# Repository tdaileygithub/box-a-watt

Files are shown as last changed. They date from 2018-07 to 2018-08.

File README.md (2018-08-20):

# box-a-watt

killawatt P4400 with 3d printed box cover, image processing and emoncms display of power usage.

# Parts List [work in progress]

- [$20 - P3 P4400 kill a watt](https://www.amazon.com/P3-P4400-Electricity-Usage-Monitor/dp/B00009MDBU)
- [$5 - Lowe's - Black Solar LED Path Light](https://www.lowes.com/pd/Portfolio-4x-Brighter-4-8-Lumen-Black-Solar-LED-Path-Light/1000398433)
- [$10 - Pi Zero W](https://www.adafruit.com/product/3400)
- [$2 - LED Backlight Small](https://www.adafruit.com/product/1626)

**Total** : $37

# Pi Setup

## Disable red camera capture led

	sudo nano /boot/config.txt
	disable_camera_led=1
	sudo reboot

# [Emoncms](https://emoncms.org) setup

## Install Emoncms package dependencies 

	sudo apt-get install apache2 mysql-server mysql-client php libapache2-mod-php php-mysql php-curl php-pear php-dev php-mcrypt php-json git-core redis-server build-essential -y

## mysql installation

	sudo mysql_secure_installation
	sudo mysqld --initialize
	sudo mysqladmin -p -u root version

	sudo mysql -u root -p
	CREATE DATABASE emoncms DEFAULT CHARACTER SET utf8;
	CREATE USER 'emoncms'@'localhost' IDENTIFIED BY 'YOUR_SECURE_PASSWORD_HERE';
	GRANT ALL ON emoncms.* TO 'emoncms'@'localhost';
	flush privileges;
	exit

## apache and php configuration

	sudo pear channel-discover pear.swiftmailer.org
	sudo pecl install swift/swift redis
	printf "extension=redis.so" | sudo tee /etc/php/7.0/mods-available/redis.ini 1>&2

	sudo phpenmod redis
	sudo a2enmod rewrite
	sudo cat <<EOF >> /etc/apache2/sites-available/emoncms.conf
	<Directory /var/www/html/emoncms>
	    Options FollowSymLinks
	    AllowOverride All
	    DirectoryIndex index.php
	    Order allow,deny
	    Allow from all
	</Directory>
	EOF
	sudo echo 'ServerName localhost' >> /etc/apache2/apache2.conf
	sudo a2ensite emoncms
	sudo service apache2 reload

	cd /var/www/
	sudo chown $USER html
	cd html
	git clone -b stable https://github.com/emoncms/emoncms.git
	cd /var/www/html/emoncms
	git pull

	sudo mkdir /var/lib/phpfiwa
	sudo mkdir /var/lib/phpfina
	sudo mkdir /var/lib/phptimeseries

	sudo chown www-data:root /var/lib/phpfiwa
	sudo chown www-data:root /var/lib/phpfina
	sudo chown www-data:root /var/lib/phptimeseries

	cd /var/www/html/emoncms/Modules
	git clone https://github.com/emoncms/dashboard.git
	git clone https://github.com/emoncms/app.git
	
	sudo touch /var/log/emoncms.log
	sudo chmod 666 /var/log/emoncms.log

## emoncms configuration

	cd /var/www/html/emoncms/
	cp default.settings.php settings.php

	nano settings.php
	$username = "emoncms";
	$password = "YOUR_SECURE_PASSWORD_HERE";
	$server   = "localhost";
	$database = "emoncms";

	http://localhost/emoncms/

# [ssocr](https://github.com/auerswal/ssocr)

[ssorc manual](https://www.unix-ag.uni-kl.de/~auerswal/ssocr/)

Used to process images captured with raspistill.

## Install ssocr dependencies 

	sudo apt-get install libimlib2-dev

## make

	cd ssocr
	make

## example command

 	./ssocr -v -d -1 -P -S -D -t 20 crop 650 410 600 500  remove_isolated erosion 3 opening 3 ../29_07_2018_00_58_47.jpg

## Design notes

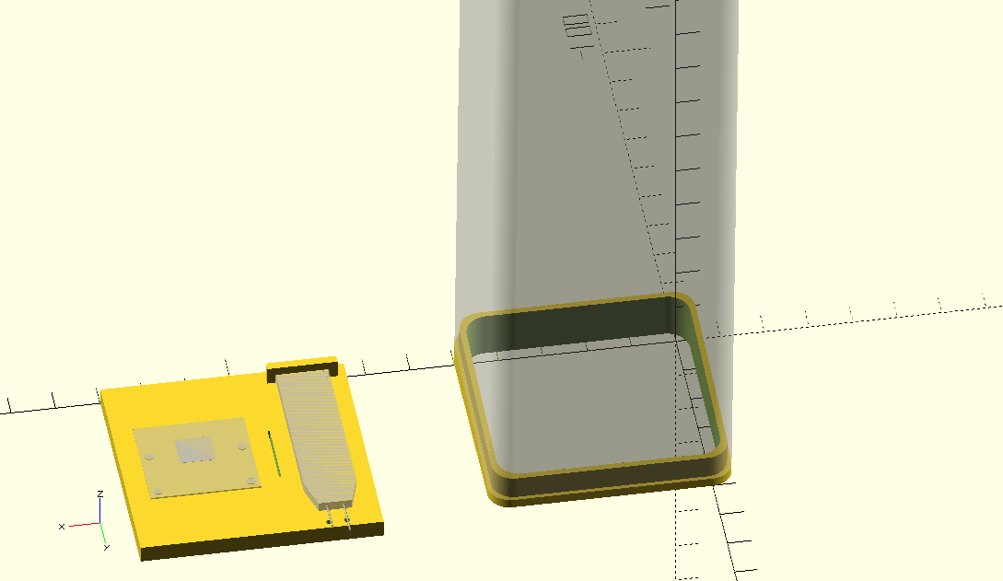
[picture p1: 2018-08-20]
models/media/box-a-watt.png

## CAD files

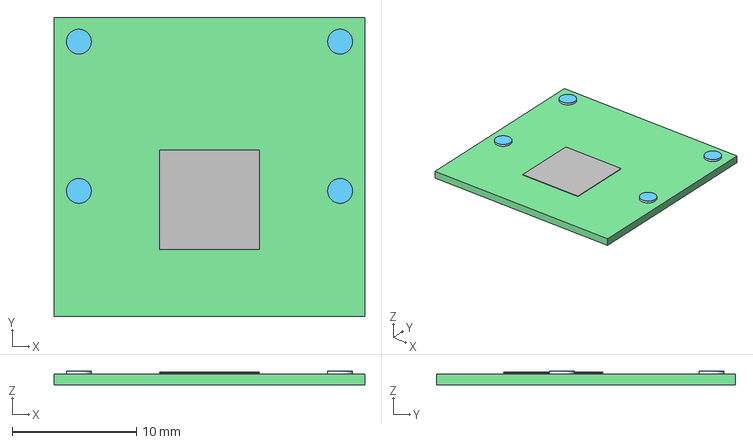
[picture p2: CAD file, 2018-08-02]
models/camera_1_3.3mf
25.0 x 24.0 x 1.14 mm

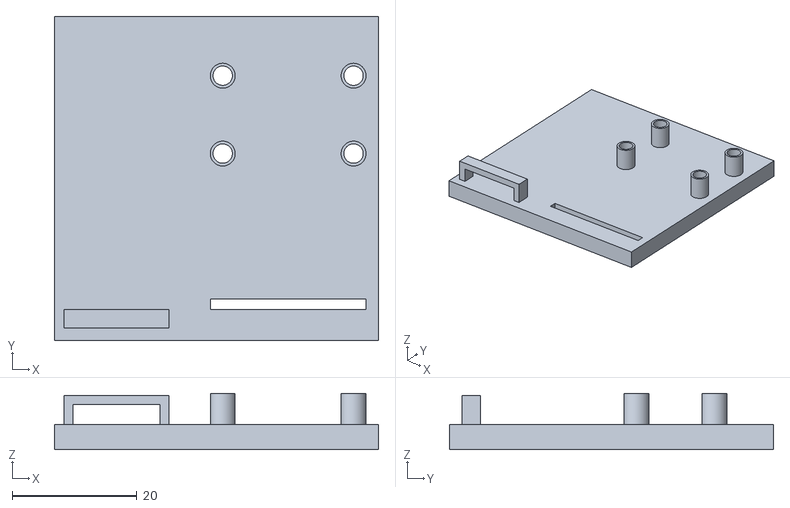
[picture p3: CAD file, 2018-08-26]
models/stl/camera_and_light_mount.stl
52.0 x 52.0 x 9.00

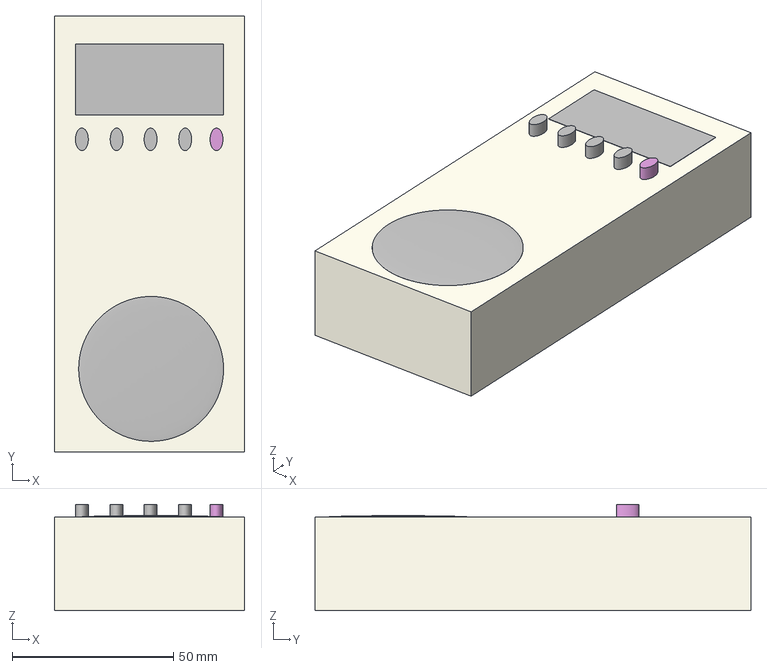
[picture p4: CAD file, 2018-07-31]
models/killawatt.3mf
59.0 x 135.4 x 33.0 mm

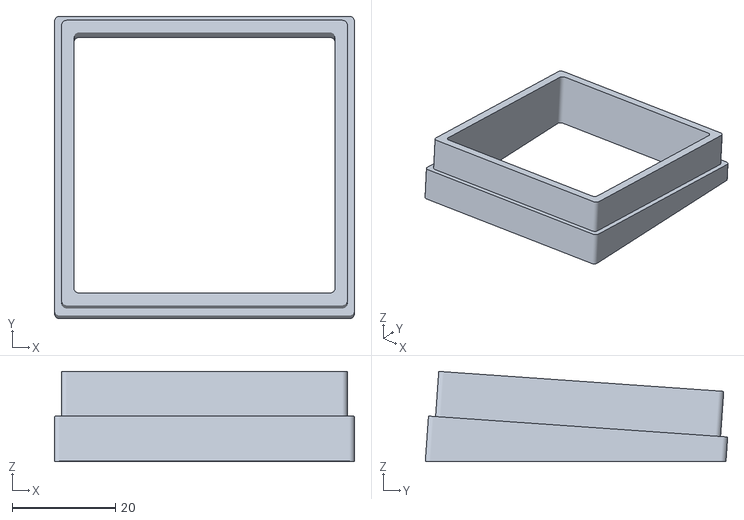
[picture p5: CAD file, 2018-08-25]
models/stl/wedge.stl
58.0 x 58.5 x 17.4

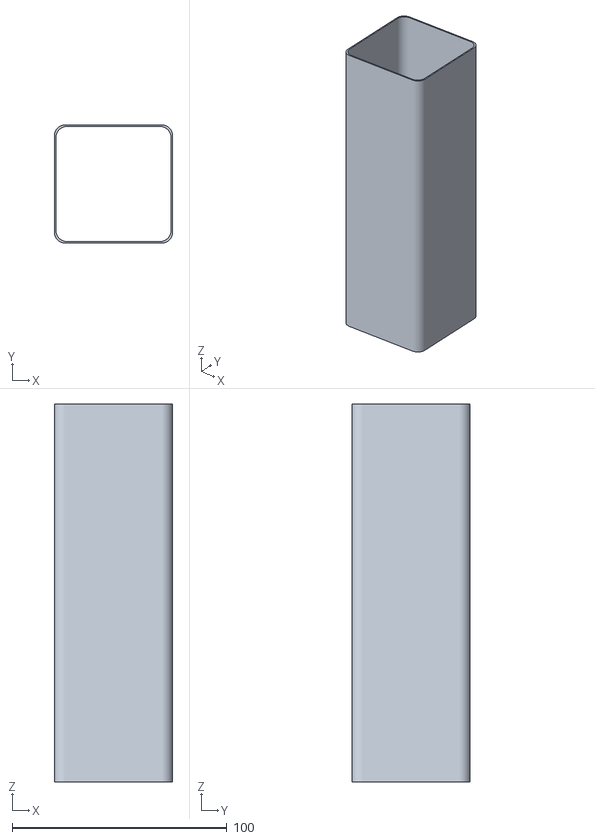
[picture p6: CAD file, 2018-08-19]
models/stl/LightBox.stl
55.0 x 55.0 x 176.0

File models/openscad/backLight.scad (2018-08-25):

// ====================================================
// Model for the Lucklight KWB-R3912W/1W backlight
// ====================================================
//                         (+) 
//                          |  (-)
//                          |  | 
//                          |  |
//                          |  |
//              X1,Y2   +----------+ X2, Y2
//                     /            \
//                    /              \
//          X0,Y1    +----------------+ X3, Y1
//                   |                |
//                   |                |
//                   |                |
//                   |                |
//                   |                |
//                   |                |
//                   |                |
//                   |                |
//                   |                |
//                   |                |
//                   |                |
//                   +----------------+
//                   X0,Y0            X3,Y0
//

backLight_width1    = 11.9;
backLight_width2    = 11.9;
backLight_width3    =  7.5;  // 11.90 to 7.5
backLight_height1   =  1.0;
backLight_height2   = 38.7; 
backLight_height3   =  7.2;
backLight_thickness = 2.20;

backLight_pin_spacing = 2.54;
backLight_pin_radius  = 0.25;
backLight_neg_pin_len = 26.5;
backLight_pos_pin_len = backLight_neg_pin_len * 1.1;

backLight_X0 = 0;
backLight_X1 = (backLight_width1 - backLight_width3)/2.0;
backLight_X2 = (backLight_width1 - backLight_X1);
backLight_X3 = backLight_width1;

backLight_Y0  = 0;
backLight_Y1  = (backLight_height1 + backLight_height2);
backLight_Y2  = (backLight_height1 + backLight_height2 + backLight_height3);


module backLight_lightArea(){
linear_extrude(height=backLight_thickness)
   polygon(
       points = [
              [backLight_X0, backLight_Y0],
              [backLight_X3, backLight_Y0],
              [backLight_X3, backLight_Y1],
              [backLight_X2, backLight_Y2],
              [backLight_X1, backLight_Y2],
              [backLight_X0, backLight_Y1]
          ]
  );
}

module backLight() {
union(){
        backLight_lightArea();

        // Negative Terminal
        translate([backLight_X2-0.25*backLight_width3,backLight_Y2-1.0,backLight_thickness/2])
            rotate([-90,0,0])cylinder(h= 8.0, r=backLight_pin_radius);

        // Positive Terminal
        translate([backLight_X1+0.25*backLight_width3,backLight_Y2-1.0,backLight_thickness/2])
            rotate([-90,0,0])cylinder(h=10.0, r=backLight_pin_radius);
}
}


module backLight_holder_bar() {
tolerance = 1.0;   // On each edge.  Total is 2mm ~ 80 mils
barHeight = 3.0;
barEnd = 2.5;      // Thickness of bar on each end

difference() {
     // Solid cube in the shape of the holding bar
     translate([-barEnd, 0, 0]) cube([backLight_width1 + 2*barEnd, barHeight, backLight_thickness+2.5]);

     // Hole with slightly bigger dimensions of than lightbar (z axis is much bigger so ends are removed cleanly)
     translate([-tolerance, -barHeight*2.5, -tolerance])cube([backLight_width1+2*tolerance, barHeight*5, backLight_thickness+2*tolerance]);
    }
}

// Until documentation is written this is how to instantiate objects
//#backLight();
//backLight_holder_bar();

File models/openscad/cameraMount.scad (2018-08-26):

module camera_module_import() {
      // Orient the camera correctly and place edge at 0,0.
      // This module wraps this position and orientation so that future
      // transforms on the camera are on the correctly oriented part instead
      // of the original stl model.
      import("../stl/camera_1_3.stl");
}

module camera_standoffs(standoffRadius, standoffHeight) {
       // According to specs, the camera mount holes are in a rectangle centered 12.5mm x 21.0mm spacing
       // The holes are for M2 screws (r>1mm) with the top/bottom clearance pad being 4mm (r=2mm).
      union() {
          translate([ 0,   0,   standoffHeight/2]) cylinder(r=standoffRadius, h=standoffHeight, center=true);
          translate([ 0,  12.5, standoffHeight/2]) cylinder(r=standoffRadius, h=standoffHeight, center=true);
          translate([21,   0,   standoffHeight/2]) cylinder(r=standoffRadius, h=standoffHeight, center=true);
          translate([21,  12.5, standoffHeight/2]) cylinder(r=standoffRadius, h=standoffHeight, center=true);
          }
}

module camera_mount(plateWidth, plateHeight, plateThickness=4.0) {

       camera_cable_width = 16.5;
       camera_cable_thickness = 0.15;
       camera_cable_width_opening = 25.0;  // Make as wide as camera
       camera_cable_thickness_opening = camera_cable_thickness + 1.5;

       standoffHeight = 5;

       difference() {
           union() {
                   cube([plateWidth, plateHeight, plateThickness]);

                   // Make a bar (4mm x 2mm) to hold the backlight in place
                   translate([4, 2, plateThickness])backLight_holder_bar();

                   // Put the camera standoffs in place so that camera lens is centered.  Standoff is 4mm in diameter.
                   translate([27,30,plateThickness]) camera_standoffs(standoffRadius=2, standoffHeight=standoffHeight);
           }
      
           // --------------------------------------------------
           // The following items are subtracted from the design
           // --------------------------------------------------

           // Remove the section for the Camera Cable Slit
           translate([50,5,-plateThickness*2.5])
               rotate([0,0,90])
                   cube([camera_cable_thickness_opening, camera_cable_width_opening, plateThickness*5]); // Cut this out of board


           // Make holes for the BackLight power and ground wires
           translate([12,53, -plateThickness*0.5])cylinder(h= plateThickness*5, r=1.0);
           translate([ 8,53, -plateThickness*0.5])cylinder(h= plateThickness*5, r=1.0);

           // Make holes for camera mount (M2 drill size is 1.55mm ~ 1/16".  The height should be large to remove all material).
           translate([27, 30, -100]) camera_standoffs(standoffRadius=1.55, standoffHeight=200);
      }


      // ----------------------------------------------------
      // Show the images of the camera and the backlight
      // but do not use them in building the working object
      // ----------------------------------------------------
      %translate([25,20, plateThickness + standoffHeight + 0.5]) camera_module_import();
      %translate([4,2,plateThickness]) backLight();
}

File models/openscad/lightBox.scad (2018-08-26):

include <rBox.scad>
include <backLight.scad>
include <cameraMount.scad>

// Measurements of the the lightbox.
// Box Dimensions (mm)
measuredInnerWidth    =  55.0;    // varies 54.7 to 55.7 (backside: 52.25mm)
measuredOuterWidth    =  58.0;    // varies 57.5 to 59.0 (backside: 58.75mm)
measuredWallThickness =   2.0;    // Backside of box is up to 3.6mm
measuredLength        = 176.0;

// For curved edges use a small radius (or 0).
// This amount is shaved off each edge and the part prints smaller.
measuredCornerRadius  =   1.0;

additionalThickness   =  15.0; 

// Return the thickness which is used in other modules
function lightBox_get_default_thickness() = additionalThickness;

// The light box is a simple hollow rectangle.  
module lightBox_model() {
rounded_hollow_box(
        width=measuredOuterWidth,
        height=measuredOuterWidth,
        length=measuredLength,
        thickness=measuredWallThickness,
        cornerRadius=measuredCornerRadius
        );
}


module lightBox_wedge(ange=0.0) {
    // Need to remove an additional 0.5mm from all inner sides.
    // Easier to add to thickness.
    innerLipPullback = 0.5;

    rounded_sloped_box_gasket(
        width=measuredOuterWidth,
        height=measuredOuterWidth,
        wallThickness=(measuredWallThickness+innerLipPullback),
        cornerRadius=measuredCornerRadius,
        additionalThickness=additionalThickness,
        angle=angle
        );
}


module lightBox_camera_mount(widthAdjustment=0, heightAdjustment=0)
{
    camera_mount(plateWidth=measuredInnerWidth+widthAdjustment, plateHeight=measuredInnerWidth+heightAdjustment, plateThickness=4.0);
}

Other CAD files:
models/openscad/main.scad
models/openscad/rBox.scad
models/stl/camera_1_3.stl
models/stl/killawatt.stl

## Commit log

2018-07-31 update readme with disable led command and add killawatt ms 3d builder file [WIP]
    [killawatt.3mf]
2018-08-02 add pi documentation git repo https://github.com/raspberrypi/documentation
2018-08-02 add camera doc https://media.readthedocs.org/pdf/picamera/latest/picamera.pdf
2018-08-02 add camera diagram pdf https://www.raspberrypi-spy.co.uk/wp-content/uploads/2013/05/Raspberry-Pi-Camera-Module-Diagram.pdf
2018-08-02 add camera module 3d model file
    [camera_1_3.3mf]
2018-08-12 add pi zero and led light docs
2018-08-19 Added openscad initial models.
    [lightBox.scad, main.scad, rBox.scad]
2018-08-19 Added STL Model.
    [EndCap.stl, LightBox.stl]
2018-08-19 add exported stl models of camera and killawatt for paul
    [camera_1_3.stl, killawatt.stl]
2018-08-20 Reworked the entire model. Generated STL. Ready for printing.
    [EndCap.stl, lightBox.scad, main.scad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]
2018-08-20 Added camera mount and light mount.
    [backLight.scad, camera_and_light_mount.stl, lightBox.scad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]
2018-08-21 Renamed and moved folders around.
    [EndCap.stl, LightBox.stl, camera_and_light_mount.stl]
2018-08-21 Moved stl files into own directory.
    [camera_1_3.stl, killawatt.stl, lightBox.scad]
2018-08-21 Openings for the backlight and camera ended up being too small on first print.
    1) Made the backlight holder bar opening a lot bigger.
    2) Made the camera cable opening a lot bigger.
    3) Rotated camera into correct orientation and position.
    [backLight.scad, lightBox.scad]
2018-08-21 Reduce the size of the radius for the curved box.
    [lightBox.scad]
2018-08-21 Updated STL for the camera/Light mount as well as the wedged endcap.
    [EndCap.stl, camera_and_light_mount.stl]
2018-08-25 Opening for the light bar was too small. Widened it up a lot to allow easy insertion.
    [backLight.scad]
2018-08-25 Replaced tabs with spaces.
    [backLight.scad]
2018-08-25 Decreased width and length of camera mount since box opening varies. Added standoffs for the camera. Spun camera 90 degrees (along with slit for camera cable).
    [lightBox.scad]
2018-08-25 Had to make wedge slightly larger (still do not know why). Increased thickness of the wall.
    [EndCap.stl, camera_and_light_mount.stl, lightBox.scad]
2018-08-25 Incorrectly using inner dimensions of box instead of outer dimensions.
    [lightBox.scad]
2018-08-25 Translating rounded box so that it always maintains same position as a rectangular box.
    [rBox.scad]
2018-08-25 Camera mount moved to its own function.
    [cameraMount.scad, lightBox.scad]
2018-08-25 Measurements of several boxes vary. Seeing large variations in box's width and height across the length as well. Added function to return default value of thickness.
    [lightBox.scad]
2018-08-25 Made the inner lip of the wedge cap larger (by adjusting the thickness of the lip).
    [EndCap.stl, lightBox.scad, main.scad]
2018-08-25 Renamed endcap to wedge - more appropriate name.
    [wedge.stl]
2018-08-25 Added width and height adjustment to the camera mount so that it can be adjusted slightly to fix in different boxes.
    [lightBox.scad]
2018-08-25 Got rid of test code. Added way to show both models together with the light box.
    [main.scad]
2018-08-26 Added Tap/Drill size chart.
2018-08-26 Adjusted camera mount for m2 screws.
    [cameraMount.scad]
2018-08-26 Removed backside face of box with hacksaw and discovered that the box dimensions are quite different from front. Adjustments and comments added.
    [lightBox.scad, main.scad]
2018-08-26 Added latest STL for camera mount.
    [camera_and_light_mount.stl]
